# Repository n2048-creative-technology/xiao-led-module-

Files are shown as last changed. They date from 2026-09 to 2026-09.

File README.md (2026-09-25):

# XIAO LED Module

A 44 x 21 mm addressable-LED panel built around a **Seeed Studio XIAO
ESP32-C3**, driving **50 WS2812B-compatible RGB LEDs** (2020 package)
arranged as two 25-LED daisy chains, plus a 4-pin JST-PH connector for
external power/data breakout.

## 3D Renders

| Top side (LED array) | Bottom side (XIAO socket) |
|---|---|
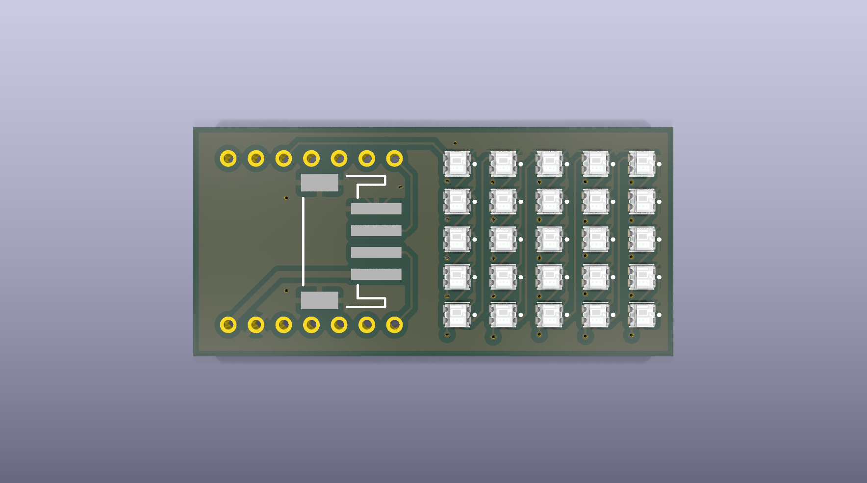
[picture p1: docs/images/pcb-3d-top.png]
PCB top 3D render
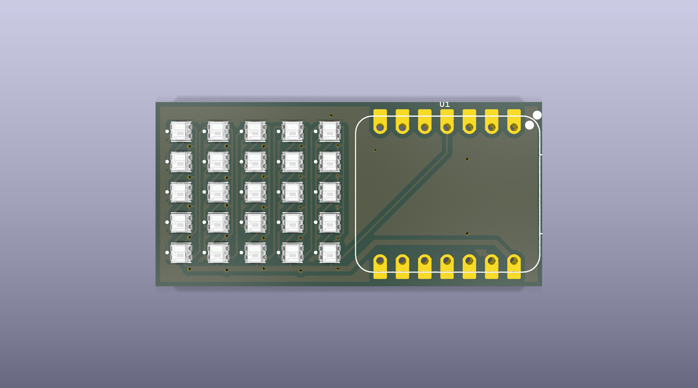
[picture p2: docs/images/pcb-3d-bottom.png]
PCB bottom 3D render
|  |  |

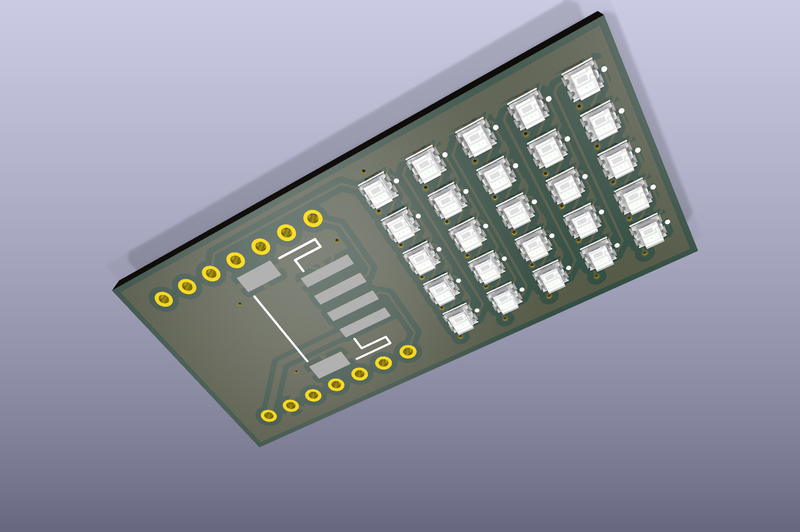
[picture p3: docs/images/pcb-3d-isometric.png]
PCB isometric 3D render


## Schematic

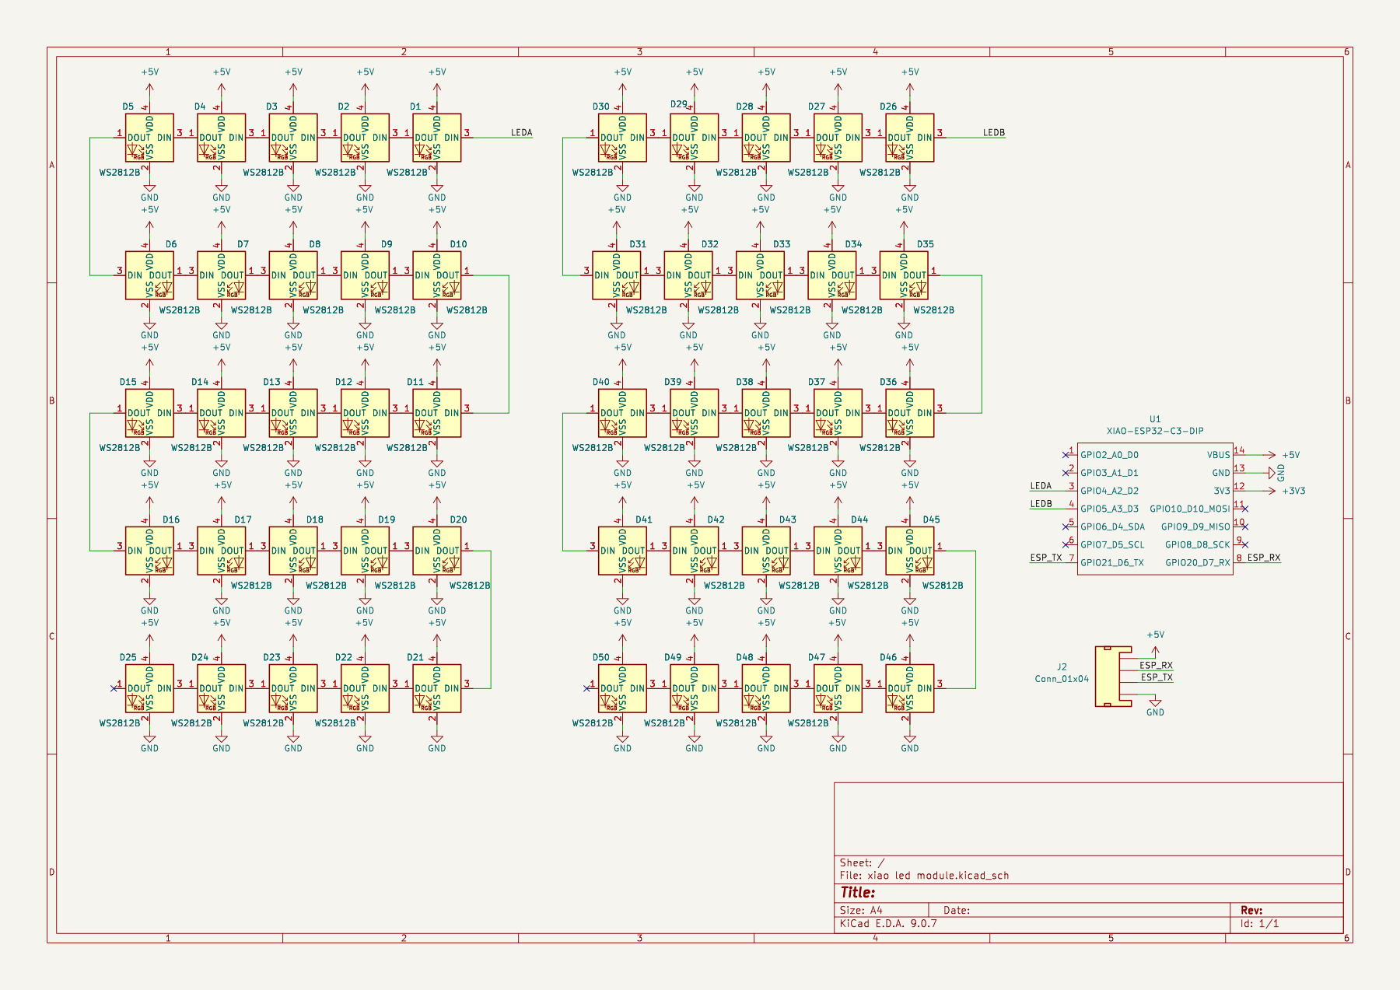
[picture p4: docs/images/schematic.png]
Schematic


Full-resolution vector version: [`docs/images/schematic.pdf`](docs/images/schematic.pdf)

## PCB Layout

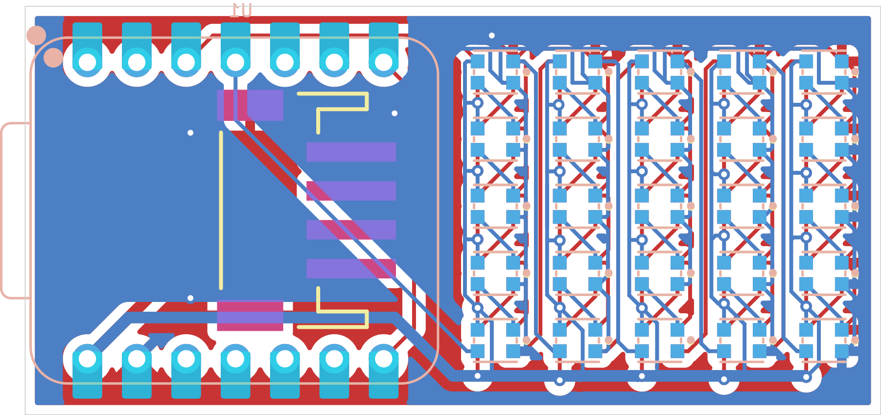
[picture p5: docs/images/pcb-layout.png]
PCB layout


*Copper (F.Cu / B.Cu), silkscreen, and solder mask layers, board outline shown.*

## Board Specs

- **Size:** 44.05 mm x 21.05 mm
- **Layers:** 2 (F.Cu / B.Cu)
- **MCU:** Seeed Studio XIAO ESP32-C3 (socketed, not soldered — see Manufacturing below)
- **LEDs:** 50x WS2812B-compatible addressable RGB LED, 2020 package,
  arranged as two independent 25-LED daisy chains (LEDA / LEDB) driven
  from separate GPIO pins
- **Power/data breakout:** J2, 4-pin JST-PH 2.0mm right-angle SMD connector
- **Power in:** +5V rail feeds the LED array; XIAO module handles its
  own onboard 3.3V regulation

## Bill of Materials

All parts verified against the live JLCPCB Open Platform API (real-time stock/pricing).

| Ref | Part | LCSC # | Library | Qty |
|---|---|---|---|---|
| D1-D50 | XL-2020RGBC-2812B (WS2812B-compatible RGB LED) | C5349955 | Extended | 50 |
| J2 | WAFER-PH2.0-4PWB (JST-PH-compatible 4-pin SMD connector) | C3029442 | Extended | 1 |
| U1 | Seeed XIAO ESP32-C3 | — | **Not JLCPCB-assembled, see below** | 1 |

### Part substitution notes

- **D1-D50 (LEDs):** the schematic's original part, WS2812B-2020
  (LCSC C965555), has only **4 units** in live JLCPCB stock — unusable
  for a 50-LED board. Replaced with **XL-2020RGBC-2812B (C5349955,
  127,770 in stock)** — confirmed via XINGLIGHT's datasheet to share
  the same 2.0x2.0mm package, the same VDD/GND/DI/DO pin-out, and
  WS2812 protocol compatibility. Direct drop-in on the existing
  `WS2812_2020` footprint.
- **J2 (connector):** the original part, JST S4B-PH-SM4-GW-TB
  (LCSC C265331), shows **0 units** in stock. Replaced with
  **WAFER-PH2.0-4PWB (C3029442, 45,426 in stock)** — same 4-pin,
  2.0mm-pitch, right-angle SMD JST-PH-compatible connector family,
  confirmed on the existing `JST_1x04_P2.0mm_Horizontal_SMD` footprint.
- **U1 (XIAO module):** the board footprint (`XIAO-ESP32-C3-DIP`) is a
  **socket pattern** — 14 pads in 2 rows at 2.54mm pitch, each with
  both a through-hole and an SMD land, designed so a plug-in XIAO
  module can be inserted rather than reflow-soldered. JLCPCB does not
  stock a machine-placeable 2.54mm female pin socket (a known
  limitation for tall THT sockets on their SMT assembly line), so **U1
  is marked DNP (Do Not Populate)** in the BOM/CPL. The board still
  gets the correct through-holes drilled; **hand-solder a standard
  1x7, 2.54mm female header pair into the U1 pads after fabrication**,
  then plug in your XIAO ESP32-C3.

## Manufacturing

`production/` contains regenerated, verified fabrication files:

- `xiao_led_module_gerbers.zip` — Gerbers + Excellon drill file
  (upload directly to JLCPCB's PCB order)
- `bom.csv` — JLCPCB-format BOM (Comment/Designator/Footprint/LCSC
  Part #) covering the 51 machine-assembled parts (50 LEDs + J2).
  **U1 is intentionally excluded** — see part substitution notes above.
- `positions.csv` — CPL / pick-and-place file, generated with
  `--exclude-dnp` so U1 is correctly omitted from placement while
  everything else retains accurate position/rotation/side data

### 3D view in KiCad

- **D1-D50 (LEDs):** the `WS2812_2020` footprint carries a real,
  present STEP model — renders correctly out of the box.
- **J2 (connector):** the SMD JST-PH "SM4" footprint family has **no
  3D model anywhere**, including KiCad's own upstream
  `kicad-packages3D` repo — a known gap in the official library, not
  something fixable from this repo. A through-hole JST-PH variant
  (`S4B-PH-K`, LCSC C157926, 18,711 in stock) *does* have a working
  model, but switching to it means a mechanical footprint change
  (SMD → THT); left as SMD per current board design.
- **U1 (XIAO module):** the footprint's bundled 3D models point at
  `${AMZPATH}`, a third-party model pack (from whoever originally
  authored this footprint) that isn't publicly distributed anywhere
  findable. Seeed's own official OPL KiCad library ships the
  *identical* footprint with the same broken reference. JLCPCB-side
  alternatives (direct XIAO ESP32-C3 module SKUs C19189385 and
  C18212168) are both essentially out of stock (0 and 1 units,
  respectively) regardless, so U1 was staying DNP either way — the
  missing 3D preview here is cosmetic only.

### Design Rule Check status

`kicad-cli pcb drc` reports 12 violations (4 starved-thermal errors on
zone-connected pads, plus silkscreen/track warnings) — all confirmed
**pre-existing** in the original committed board, unrelated to this
sourcing pass (verified via `git stash` diff-check: identical
violation set before and after the BOM/CPL changes). No new errors
introduced by the part substitutions.

## Repo Layout

```
xiao led module.kicad_pro   KiCad project
xiao led module.kicad_sch   Schematic
xiao led module.kicad_pcb   PCB layout
docs/images/                 Renders and diagrams (this README)
production/                   JLCPCB-ready fabrication output:
  xiao_led_module_gerbers.zip    Gerbers + drill (upload as-is)
  bom.csv                        JLCPCB BOM (50 LEDs + J2; U1 excluded, DNP)
  positions.csv                  CPL / pick-and-place file (DNP-excluded)
  gerbers/                       Individual Gerber/drill layer files
```

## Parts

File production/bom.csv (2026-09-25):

Comment | Designator | Footprint | LCSC Part #
WS2812B | D1,D2,D3,D4,D5,D6,D7,D8,D9,D10,D11,D12,D13,D14,D15,D16,D17,D18,D19,D20,D21,D22,D23,D24,D25,D26,D27,D28,D29,D30,D31,D32,D33,D34,D35,D36,D37,D38,D39,D40,D41,D42,D43,D44,D45,D46,D47,D48,D49,D50 | WS2812_2020 | C5349955
Conn_01x04 | J2 | JST_1x04_P2.0mm_Horizontal_SMD | C3029442

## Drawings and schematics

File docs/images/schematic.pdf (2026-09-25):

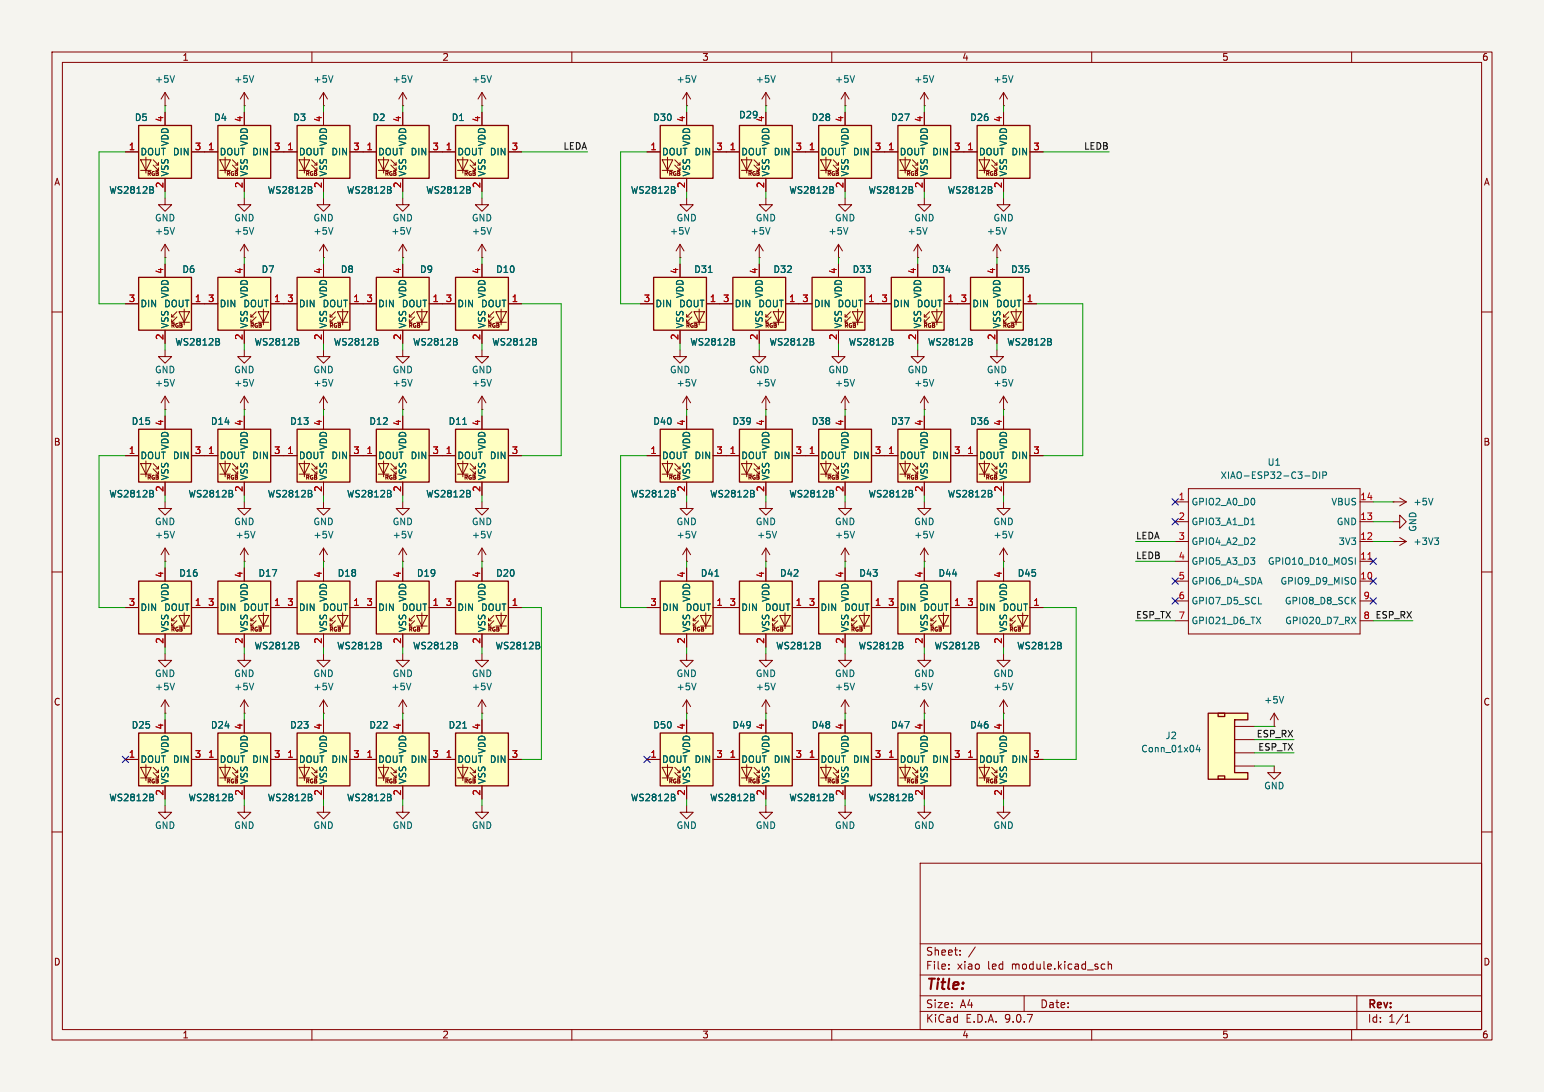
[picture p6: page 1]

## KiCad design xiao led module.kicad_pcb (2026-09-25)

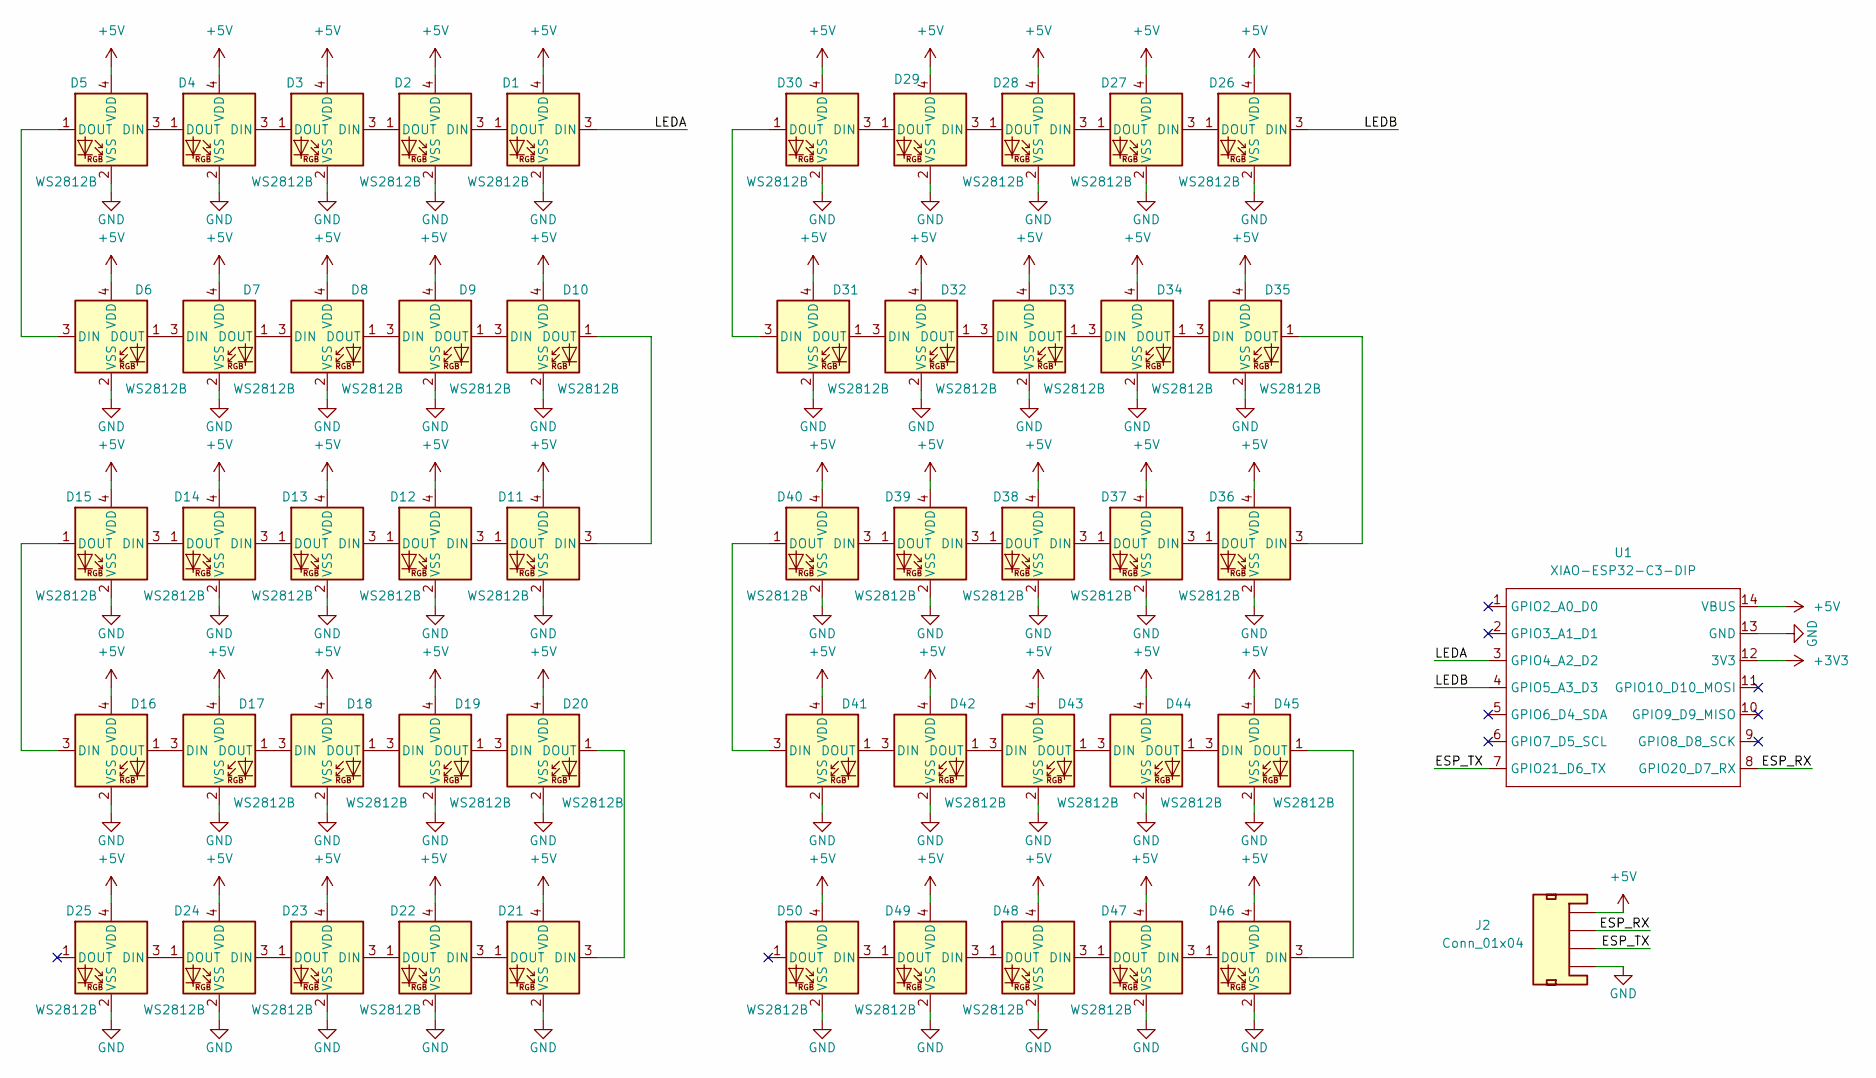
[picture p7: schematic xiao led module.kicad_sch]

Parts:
D1, D2, D3, D4, D5, D6, D7, D8, D9, D10, D11, D12, D13, D14, D15, D16, D17, D18, D19, D20, D21, D22, D23, D24, D25, D26, D27, D28, D29, D30, D31, D32, D33, D34, D35, D36, D37, D38, D39, D40, D41, D42, D43, D44, D45, D46, D47, D48, D49, D50: WS2812B; WS2812_2020; MPN XL-2020RGBC-2812B; LCSC C5349955
J2: Conn_01x04; JST_1x04_P2.0mm_Horizontal_SMD; MPN WAFER-PH2.0-4PWB; LCSC C3029442
U1: XIAO-ESP32-C3-DIP; MPN DNP - hand-solder 2x 1x7 2.54mm female 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

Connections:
+3V3: U1.12 (3V3)
+5V: D1.4 (VDD), D2.4 (VDD), D3.4 (VDD), D4.4 (VDD), D5.4 (VDD), D6.4 (VDD), D7.4 (VDD), D8.4 (VDD), D9.4 (VDD), D10.4 (VDD), D11.4 (VDD), D12.4 (VDD), D13.4 (VDD), D14.4 (VDD), D15.4 (VDD), D16.4 (VDD), D17.4 (VDD), D18.4 (VDD), D19.4 (VDD), D20.4 (VDD), D21.4 (VDD), D22.4 (VDD), D23.4 (VDD), D24.4 (VDD), D25.4 (VDD), D26.4 (VDD), D27.4 (VDD), D28.4 (VDD), D29.4 (VDD), D30.4 (VDD), D31.4 (VDD), D32.4 (VDD), D33.4 (VDD), D34.4 (VDD), D35.4 (VDD), D36.4 (VDD), D37.4 (VDD), D38.4 (VDD), D39.4 (VDD), D40.4 (VDD), D41.4 (VDD), D42.4 (VDD), D43.4 (VDD), D44.4 (VDD), D45.4 (VDD), D46.4 (VDD), D47.4 (VDD), D48.4 (VDD), D49.4 (VDD), D50.4 (VDD), J2.1, U1.14 (VBUS)
/ESP_RX: J2.2, U1.8 (GPIO20_D7_RX)
/ESP_TX: J2.3, U1.7 (GPIO21_D6_TX)
/LEDA: D1.3 (DIN), U1.3 (GPIO4_A2_D2)
/LEDB: D26.3 (DIN), U1.4 (GPIO5_A3_D3)
GND: D1.2 (VSS), D2.2 (VSS), D3.2 (VSS), D4.2 (VSS), D5.2 (VSS), D6.2 (VSS), D7.2 (VSS), D8.2 (VSS), D9.2 (VSS), D10.2 (VSS), D11.2 (VSS), D12.2 (VSS), D13.2 (VSS), D14.2 (VSS), D15.2 (VSS), D16.2 (VSS), D17.2 (VSS), D18.2 (VSS), D19.2 (VSS), D20.2 (VSS), D21.2 (VSS), D22.2 (VSS), D23.2 (VSS), D24.2 (VSS), D25.2 (VSS), D26.2 (VSS), D27.2 (VSS), D28.2 (VSS), D29.2 (VSS), D30.2 (VSS), D31.2 (VSS), D32.2 (VSS), D33.2 (VSS), D34.2 (VSS), D35.2 (VSS), D36.2 (VSS), D37.2 (VSS), D38.2 (VSS), D39.2 (VSS), D40.2 (VSS), D41.2 (VSS), D42.2 (VSS), D43.2 (VSS), D44.2 (VSS), D45.2 (VSS), D46.2 (VSS), D47.2 (VSS), D48.2 (VSS), D49.2 (VSS), D50.2 (VSS), J2.4, J2.NC1, J2.NC2, U1.13 (GND)
unnamed: D1.1 (DOUT), D2.3 (DIN)
unnamed: D2.1 (DOUT), D3.3 (DIN)
unnamed: D3.1 (DOUT), D4.3 (DIN)
unnamed: D4.1 (DOUT), D5.3 (DIN)
unnamed: D5.1 (DOUT), D6.3 (DIN)
unnamed: D6.1 (DOUT), D7.3 (DIN)
unnamed: D7.1 (DOUT), D8.3 (DIN)
unnamed: D8.1 (DOUT), D9.3 (DIN)
unnamed: D9.1 (DOUT), D10.3 (DIN)
unnamed: D10.1 (DOUT), D11.3 (DIN)
unnamed: D11.1 (DOUT), D12.3 (DIN)
unnamed: D12.1 (DOUT), D13.3 (DIN)
unnamed: D13.1 (DOUT), D14.3 (DIN)
unnamed: D14.1 (DOUT), D15.3 (DIN)
unnamed: D15.1 (DOUT), D16.3 (DIN)
unnamed: D16.1 (DOUT), D17.3 (DIN)
unnamed: D17.1 (DOUT), D18.3 (DIN)
unnamed: D18.1 (DOUT), D19.3 (DIN)
unnamed: D19.1 (DOUT), D20.3 (DIN)
unnamed: D20.1 (DOUT), D21.3 (DIN)
unnamed: D21.1 (DOUT), D22.3 (DIN)
unnamed: D22.1 (DOUT), D23.3 (DIN)
unnamed: D23.1 (DOUT), D24.3 (DIN)
unnamed: D24.1 (DOUT), D25.3 (DIN)
unnamed: D26.1 (DOUT), D27.3 (DIN)
unnamed: D27.1 (DOUT), D28.3 (DIN)
unnamed: D28.1 (DOUT), D29.3 (DIN)
unnamed: D29.1 (DOUT), D30.3 (DIN)
unnamed: D30.1 (DOUT), D31.3 (DIN)
unnamed: D31.1 (DOUT), D32.3 (DIN)
unnamed: D32.1 (DOUT), D33.3 (DIN)
unnamed: D33.1 (DOUT), D34.3 (DIN)
unnamed: D34.1 (DOUT), D35.3 (DIN)
unnamed: D35.1 (DOUT), D36.3 (DIN)
unnamed: D36.1 (DOUT), D37.3 (DIN)
unnamed: D37.1 (DOUT), D38.3 (DIN)
unnamed: D38.1 (DOUT), D39.3 (DIN)
unnamed: D39.1 (DOUT), D40.3 (DIN)
unnamed: D40.1 (DOUT), D41.3 (DIN)
unnamed: D41.1 (DOUT), D42.3 (DIN)
unnamed: D42.1 (DOUT), D43.3 (DIN)
unnamed: D43.1 (DOUT), D44.3 (DIN)
unnamed: D44.1 (DOUT), D45.3 (DIN)
unnamed: D45.1 (DOUT), D46.3 (DIN)
unnamed: D46.1 (DOUT), D47.3 (DIN)
unnamed: D47.1 (DOUT), D48.3 (DIN)
unnamed: D48.1 (DOUT), D49.3 (DIN)
unnamed: D49.1 (DOUT), D50.3 (DIN)

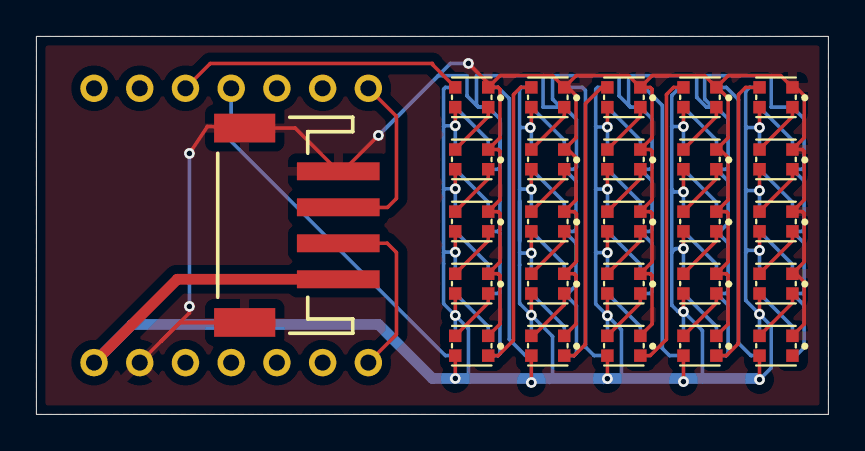
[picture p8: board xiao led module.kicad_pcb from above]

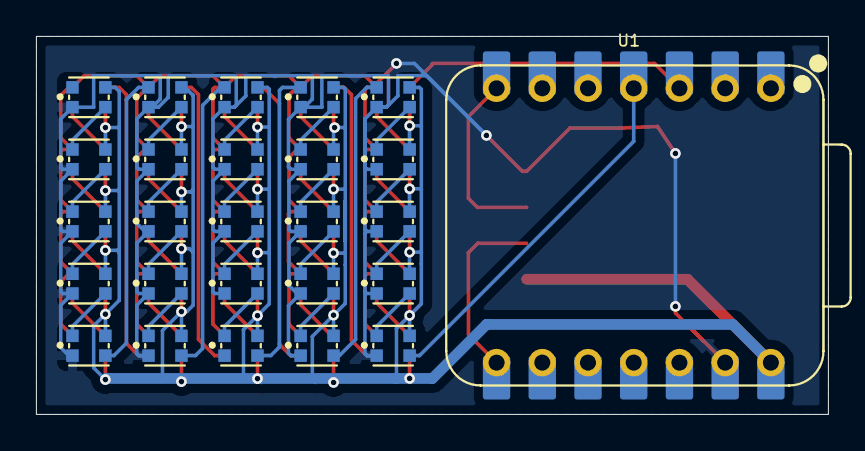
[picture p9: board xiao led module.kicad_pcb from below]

Board: 2 copper layers, 44.0 x 21.0 mm, 52 parts (26 on the bottom side), 54 nets.

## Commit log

2026-09-25 kicad project
    [bom.csv, designators.csv, positions.csv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]
2026-09-25 Source all BOM parts against live JLCPCB stock, generate fab files & docs
    Re-sourced every part on the XIAO LED module board against the live
    JLCPCB Open Platform API and generated complete, verified fabrication
    files. The prior BOM/CPL (from Fabrication Toolkit) had an empty LCSC
    Part # column, same issue seen on the esp32-c3-led board.
    Part substitutions:
    - D1-D50 (WS2812B-2020 LEDs): original part LCSC C965555 has only 4
    units in stock -- unusable for a 50-LED board. Replaced with
    XL-2020RGBC-2812B (C5349955, 127,770 in stock), confirmed via
    XINGLIGHT datasheet: same 2.0x2.0mm package, same VDD/GND/DI/DO
    pinout, WS2812-protocol compatible. Direct drop-in on the existing
    WS2812_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
    [bom.csv, designators.csv, positions.csv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]
2026-09-25 Document 3D-model availability audit for JLCPCB-sourced parts
    Investigated 3D view support for every BOM part per user request
    (components should have working KiCad 3D models AND be available as
    JLCPCB parts):
    - D1-D50 (LEDs, XL-2020RGBC-2812B): WS2812_2020 footprint already has
    a real, present STEP model. No change needed.
    - J2 (connector, WAFER-PH2.0-4PWB): confirmed the SMD JST-PH 'SM4'
    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
